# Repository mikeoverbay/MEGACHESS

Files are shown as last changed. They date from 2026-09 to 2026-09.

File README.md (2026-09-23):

# Megachess

Chess on an Arduino Mega 2560 R3 with the DIYables 3.5" 480x320 touch shield.

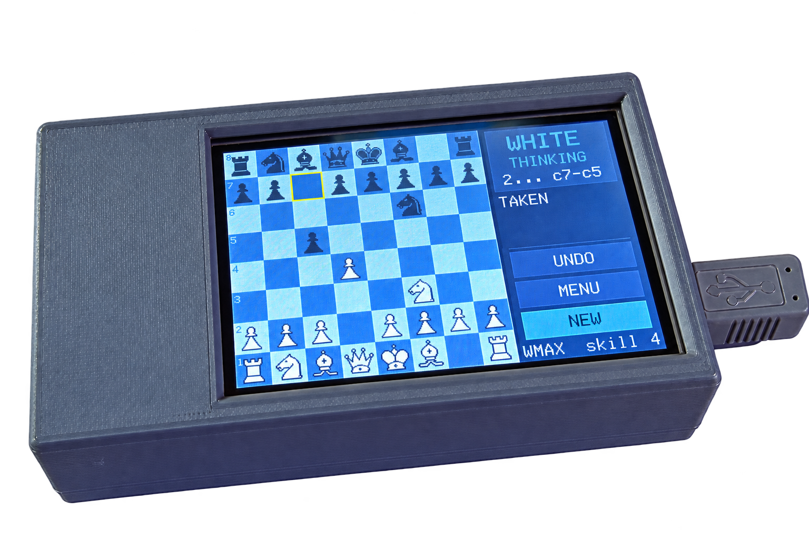
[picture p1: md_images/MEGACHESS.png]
Megachess in its case, mid-game


Tap a piece, tap where it goes. Play the engine, play a friend on the one
screen, or let the engine play itself. Five board themes, a saved game you can
resume after a power cut, a PGN log of every finished game, and an opening book
— the last three from the SD card.

| | |
|---|---|
| rules, and the search at SKILL 1–2 | [MicroChess](https://github.com/ripred/MicroChess) by Trent M. Wyatt, MIT, in `src/engine` |
| the search at SKILL 3–7 | [micro-Max 4.8](http://home.hccnet.nl/h.g.muller/max-src2.html) by H.G. Muller, in `src/umax` |
| display and touch | DIYables_TFT_Touch_Shield 2.2.1 |
| artwork, UI, storage, engine glue | this sketch |

Built for `arduino:avr:mega`. Current size: **76.4 KB flash (30%)**, **4729 B
RAM (57%)**, leaving 3.4 KB for the searches' recursion; micro-Max was measured
using up to 1.9 KB of that.

---

## Parts

| part | notes |
|---|---|
| Arduino Mega 2560 R3 | the 256 KB of flash and the SPI on pins 50–52 are why it is a Mega and not an Uno |
| DIYables 3.5" 480x320 TFT touch shield | resistive touch, microSD slot; HX8357D driver on current units, RM68140 on earlier ones ([product page](https://diyables.io/products/3.5-320x480-tft-lcd-color-touch-screen-shield-for-arduino-uno-mega)) |
| microSD card | any size from 1 GB up, FAT32 with MBR; it needs under half a megabyte. Built with a 16 GB card. Plus a reader for the PC |
| 3 short wires, soldered | on the underside of the Mega, pins 50, 51, 52 to D12, D11, D13 — see below. The case leaves no room for jumper wires on the headers |
| USB A-to-B cable | powers it and programs it |
| stylus | optional; a fingernail works on the resistive panel |
| the printed case | two parts, see [The case](#the-case) |

Software: Arduino IDE 2 (its bundled arduino-cli does the builds here), the
DIYables_TFT_Touch_Shield library 2.2.1 and the SD library 1.3.0, Python 3 with
Pillow for the tools (skia-python as well to re-render the piece art), and,
only for the simulator, Visual Studio's C++ compiler.

---

## Building it

### In the Arduino IDE

1. Get the folder onto your machine, as a clone or a zip, and keep its name
   `Megachess`: the IDE wants the folder and its `.ino` to match.
2. **Tools > Board > Arduino AVR Boards > Arduino Mega or Mega 2560**, and
   **Tools > Port** to the Mega.
3. **Sketch > Include Library > Manage Libraries**, search
   *DIYables_TFT_Touch_Shield*, install **2.2.1**. The SD library comes with
   the IDE.
4. Open `Megachess.ino`. The engines in `src/engine` and `src/umax` compile
   along with it; nothing to add.
5. Check `megachess.h` names your shield's driver (see *Run this first*),
   then **Upload**.

The Serial Monitor at 115200 shows the boot report, and while you play, one
line per engine move. Close it before an upload if the upload times out: it
holds the port.

The other sketches open the same way: `bringup/bringup.ino`, and
`umaxbench/umaxbench.ino` after running `sh tools/umax_bench.sh` once, which
copies the engine into it.

### From the command line

The IDE bundles `arduino-cli`; every command below works with it. Compile
and upload the game:

```bash
arduino-cli compile -b arduino:avr:mega --upload -p COM8 .
```

## Run this first

```bash
arduino-cli compile -b arduino:avr:mega --upload -p COM8 bringup
```

`bringup/bringup.ino` answers the three things that have to be true before the
game is worth running.

**1. Which driver IC?** DIYables ship this board with an RM68140 (early units)
or an HX8357D (later ones, after a chip shortage). Both use library 2.x and
share an API — only the class name differs, and the wrong one gives a blank or
garbled screen. The sketch paints a card for each; tap whichever renders
correctly and it prints the line to paste into `megachess.h`:

```c
#define MEGACHESS_DRIVER_RM68140     // or MEGACHESS_DRIVER_HX8357D
```

The default is RM68140. If *neither* card renders, you have the older,
discontinued ILI9488 shield, which needs library **v1.0.0** instead — that
version has the `DIYables_TFT_ILI9488_Shield` class this one dropped.

**2. Does touch land where you press?** After you tap, it switches to a touch
test with corner targets. If the crosshair sits off them, run the library's
`TouchCalibration` example and paste its four numbers into `ui_begin()` in
[ui.cpp](ui.cpp).

**3. Is the SD card reachable?** Checked at boot, reported on Serial at 115200.
Expect it to fail until you add three wires — see below.

---

## The SD card needs three jumpers on a Mega

This is DIYables' own note, not a fault:

> On Arduino Mega, the microSD card slot (D10–D13) does not work without extra
> wiring because the Mega's SPI pins are on D50–D53.

The shield's SD lines sit on the Uno SPI footprint. The Mega's hardware SPI is
elsewhere, so bridge them:

| Mega pin | to shield pin | signal |
|---|---|---|
| 50 | D12 | MISO |
| 51 | D11 | MOSI |
| 52 | D13 | SCK |
| — | D10 | CS — ordinary GPIO, already fine |

Jumper wires on the headers will do for a test on the bench, but the case
has no room for them: solder three short wires on the underside of the Mega,
from the pads of 50, 51 and 52 to the pads of D12, D11 and D13.

**Everything works without the card.** You lose the SD-loaded artwork (the
built-in 1-bit pieces stand in), saving, the PGN log and the opening book. The
chess is untouched.

### What goes on the card

FAT32, MBR — which is what yours already is. Written for you:

```
/PIECES/AMBER.SET        full-colour piece artwork, one per theme
/PIECES/CLASSIC.SET
/PIECES/POCKET.SET
/PIECES/SLATE.SET
/PIECES/VECTOR.SET
/MCHESS/BOOK.TXT         opening lines, editable
/MCHESS/SAVE.DAT         written as you play, removed when a game ends
/MCHESS/SETTINGS.DAT     mode, skill, theme, orientation, touch calibration
/MCHESS/GAMES.PGN        every finished game, appended
/IMAGES/SPLASH.IMG       boot picture, optional: tools/LOGO.png through tools/splash.py
```

`SD_DATA/` in the repo is this card, file for file; copy it over. MCHESS is
the firmware's own folder and it creates it; IMAGES is yours. Every name
is 8.3 on purpose: the Arduino SD library cannot open anything longer, folders
included, and it fails without a word. The folder was MEGACHESS once, and the
Mega never read or wrote a byte in it. The simulator refuses such names too.

---

## Playing

**Menu.** Mode (vs engine / 2 player / engine demo), skill 1–7 (1–2 is
MicroChess searching that many plies, 3–7 is micro-Max on a clock of 1, 2.5, 5,
10 or 20 seconds — the label says which), which colour you take, theme, board
orientation. `RESUME` lights up when the card
holds an unfinished game.

**Board.** Tap a piece to pick it up — its legal destinations appear as dots,
and a circle around each piece it can take. Tap a destination to play it, tap the
piece again to put it down, or tap another of your pieces to switch. The last
move keeps an amber border; a king in check gets a red one.

**UNDO** steps back a full move in vs-engine mode (yours *and* the engine's
reply), one half-move otherwise. Four half-moves are kept.

Pawns auto-queen — the engine has no underpromotion, so there is no piece
picker to show you.

### A quirk worth knowing

MicroChess scores "moved and left my own king attacked" as an immediate loss
rather than an illegal move. That is fine for the engine, but it would mean a
mis-tap loses you the game, so `apply_move()` plays the move, checks your king,
and takes it straight back with **KING IN CHECK** if it hangs.

The move dots are the engine's pseudo-legal list, so a square that would hang
your king still shows a dot. Filtering them properly needs a trial move per
destination — about a second per piece on a 16 MHz AVR — which is why the check
happens on the tap instead.

---

## Themes and artwork

Five themes, switchable from the menu, defaulting to **Amber**. Board colours
live in [themes_gen.h](themes_gen.h); the matching pieces are on the card.

The card artwork is the **Alpha** chess set by Eric Bentzen, as shipped in
lichess (`public/piece/alpha`, free to use), rasterised per theme by
[tools/svgpieces.py](tools/svgpieces.py): each SVG's fills and strokes are
substituted with the theme's piece colours, rendered at 8x through Skia, and
LANCZOS-downsampled to 40x40. To rebuild after a theme change:

```bash
python tools/svgpieces.py alpha alpha H:\PIECES
```

Card artwork is 40x40 RGB565 **with an alpha channel**, blended against the
square underneath as it is drawn. That is why pieces have clean antialiased
edges on both light and dark squares — a colour-key cutout cannot do that. The
built-in fallback is three 1-bit layers (body, rim, internal detail), which
keeps a black piece reading as a dark silhouette rather than a light-outlined
one on a light square.

To change colours or add a theme, edit `THEMES` in [tools/themes.py](tools/themes.py) and:

```bash
python tools/build_assets.py H:\
```

That rewrites the `.SET` files, `pieces_bmp.h` and `themes_gen.h` from the one
table, so the card and the firmware cannot drift apart. `python tools/mock2.py`
renders PNG mockups at the real 480x320 to check a theme without flashing.

---

## The opening book

`/MCHESS/BOOK.TXT` — one opening per line, long algebraic, `#` for comments:

```
e2e4 e7e5 g1f3 b8c6 f1c4 g8f6 d2d3 f8c5 c2c3 d7d6
d2d4 g8f6 c2c4 g7g6 b1c3 f8g7 e2e4 d7d6 g1f3 e8g8
```

When the game so far matches the start of a line, the engine plays that line's
next move, choosing at random among all matching lines so it varies. Once play
leaves the book it stops looking and searches normally.

The 33 shipped lines were checked move-by-move with `python-chess` — 330 plies,
all legal. Lines you add are *not* validated: an illegal move is ignored and
the engine searches instead.

This replaces MicroChess's built-in book, which was one hard-coded line for one
side (`options.openbook` is left off).

---

## PGN log

Finished games append to `/MCHESS/GAMES.PGN`. Moves are written in **long
algebraic** (`e2e4`, `Nb1c3`, `Bf1xc4`), not strict SAN — it needs no
disambiguation pass, and lichess, SCID and ChessBase all import it. If you want
strict SAN, the place to add it is `lan()` in [storage.cpp](storage.cpp).

---

## Two engines

MicroChess is the rules. It generates the move list you see as dots, plays
every move, and detects check, mate and repetition. At SKILL 1 and 2 it also
chooses the engine's move, searching 1 or 2 plies.

From SKILL 3 up the move comes from micro-Max 4.8, H.G. Muller's engine in
under 2 KB of C, in `src/umax`. On the engine's turn the position is copied
onto micro-Max's own 0x88 board, it searches for the level's clock, and the
move it names is played through MicroChess exactly as a human's would be:
checked against MicroChess's move list for that piece first. Should the two
ever disagree, MicroChess's own search decides and a line saying so goes to
Serial. In a 126-move simulator game between two micro-Max sides that never
happened.

The Mega runs micro-Max at about 700 nodes a second. Measured with
`umaxbench`: a 2.5 s clock reaches depth 3 to 4, a 10 s clock depth 4 to 5.
The clock is a budget, not a limit. The engine starts another pass while less
than a third of it has gone, and a hard stop at one and a half times the
budget unwinds the search with the best move so far. Touching the panel while
it thinks does the same, so MENU works mid-think.

Each micro-Max move prints one line to Serial at 115200: depth, score, nodes,
time, and how close the stack came to the heap.

`sh tools/umax_bench.sh -u -p COM8` builds and uploads `umaxbench`, a self-play
benchmark that prints those figures for two clocks.

`src/umax/umax.cpp` is the upstream text line for line with every change marked
`MEGA`; its header lists them: a 128-entry hash with 32-bit keys, the key table
in flash, time-based deepening with a hard stop, the repetition locks moved out
of the search into a short list that recycles its oldest entry, and the console
I/O replaced by the calls in `umax.h`. The author publishes the source on his site for people to learn from
and port, with no formal licence text; chessprogramming.org lists it as open
source, and ports such as [mcu-max](https://github.com/Gissio/mcu-max) release
theirs under MIT. This copy keeps the file header, feature list and URL intact
and claims nothing beyond the changes marked `MEGA`.

---

## Two patches to the engine

`src/engine` is upstream MicroChess apart from these. Both are marked
`// Megachess:` in the source.

**1. The debug pins are the display bus.** Upstream drives LEDs on 3, 4, 5, 8
and a WS2811 strip on 6 — every one of those is part of the shield's 8-bit
parallel data bus. `MicroChess.h` sets them all to `0xFF`, and `direct_write()`
in `chessutil.cpp` returns early on that value. Without it, `direct_write()`'s
raw `PORTD`/`PORTB` writes land on whatever those bits are on a Mega, which is
not where the Uno pin numbers point.

**2. `led_strip.cpp` is stubbed.** Its FastLED path compiles on AVR and
`FastLED.show()` bit-bangs pin 6 — D6 of the display bus — mid-render. The stub
also drops FastLED's 192-byte `leds[]` array.

`MicroChess.ino` became `engine.cpp` with `setup()`/`loop()` removed (the
upstream `setup()` runs an entire game, blocking on Serial for human moves).
Two forward declarations were added: as a `.ino` the Arduino build hoisted a
prototype for every function, and a `.cpp` gets no such favour.

Everything else — move generation, alpha-beta, quiescence, castling, en
passant, repetition — is untouched upstream code.

---

## The case

Two parts in `case/`, the author's own design in Shapr3D for exactly this
stack: a Mega 2560 with the shield on it.

| file | outside size | triangles |
|---|---|---|
| [top.stl](case/top.stl) | 113.9 x 66.3 x 20.0 mm | 9,460 |
| [bottom.stl](case/bottom.stl) | 113.9 x 66.3 x 9.6 mm | 60,528 |

Open either file on GitHub and it shows in 3D: drag to turn it, and the
toolbar switches to wireframe.

`case.step` is the model itself, both parts, straight out of Shapr3D, for
anyone who wants to change it: a STEP opens in any CAD program as solids,
where an STL is only the skin.

Closed it is 113.9 x 66.3 x 29.6 mm, about 6 mm around the Mega's 101.6 x
53.3 mm board. The top is the shell: a window for the screen and two cut-outs
on the short end for the USB socket and the power jack. The bottom is the
plate: four posts for the Mega's mounting holes, slots for air, and a rim that
registers inside the top.

`case.gcode` is both parts on one bed, sliced in Cura 5.2.1 for a Creality
Ender 3 Pro (Marlin flavour): 0.2 mm layers, 10% grid infill, no supports,
225 °C nozzle, 50 °C bed, 15.8 m of filament, 3 h 44 min. It prints a draft
shield 6 mm out from the parts and 10 mm high, which keeps the corners from
curling as the print shrinks. `case.3mf` is the Cura project behind it: both
parts placed on the bed with every setting, so a different printer or
filament is one change and a reslice.

---

## Layout

```
Megachess.ino     app state machine, engine glue, setup/loop
megachess.h       geometry, theme struct, cross-file API
ui.cpp            board, panel, menu, hit testing
storage.cpp       SD: artwork, settings, save/resume, PGN, book
themes_gen.h      generated - theme table
pieces_bmp.h      generated - 1-bit fallback artwork
bringup/          hardware bring-up sketch, run first
tools/            asset generators, the mockup renderer, the micro-Max key
                  table generator and benchmark script
umaxbench/        micro-Max speed and stack benchmark for the Mega
case/             the printed case: STEP model, two STL parts, Cura project, sliced gcode
src/engine/       MicroChess
src/umax/         micro-Max 4.8, fitted to the AVR
```

Screen is 480x320 landscape (rotation 1): board 320x320 at 40px a square,
panel 160 wide on the right. The 40px square is why pieces blit with no
scaling.

When the engine moves, the square it leaves flips to the opposite square
colour three times with the piece still on it, the board repaints, and the
square it lands on flips three times. Your own moves get no announcement.

### RAM

`UNDO_SLOTS` in `megachess.h` is 4. Each slot is a `board_t` + `game_t`
snapshot, so raising it costs real memory — and the engine checks free RAM at
runtime to decide how deep to search (`options.low_mem_limit`, 810 bytes), so
squeezing the stack makes it play *worse*, quietly. Re-read the compiler's RAM
line after changing it.

`src/umax` adds 1.4 KB of globals: the hash table (`U` entries of 9 bytes in
`umax.cpp`, 128 of them), the board, and a list of the last 24 game positions
for repetition detection. Doubling `U` to 256 left
2.3 KB for the stack, and micro-Max alone was measured using up to 1.9 KB of it
on a 10 s clock, so 128 it is.

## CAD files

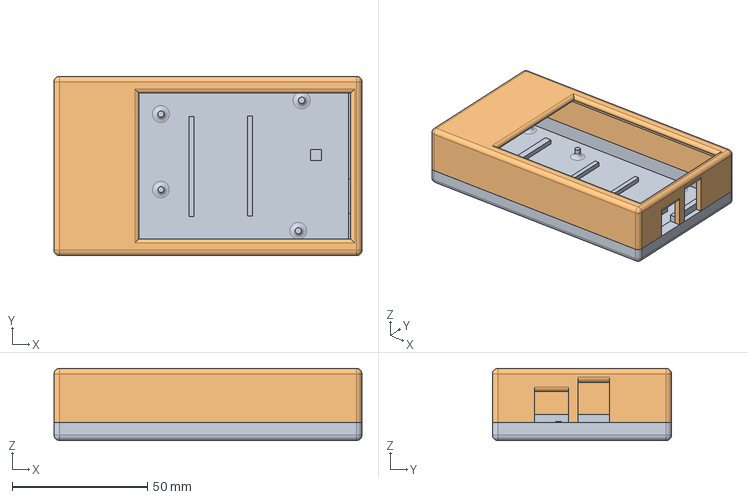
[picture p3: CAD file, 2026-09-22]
case/case.step
113.9 x 66.3 x 26.6 mm

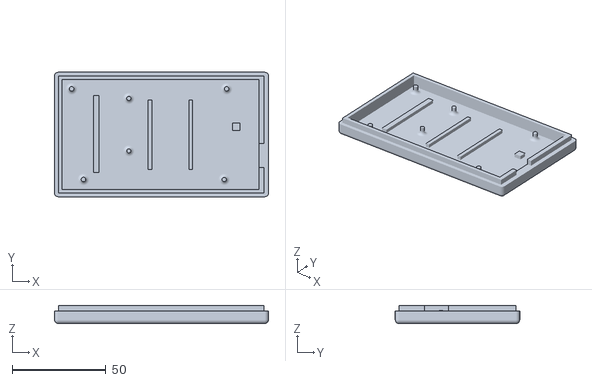
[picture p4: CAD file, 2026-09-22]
case/bottom.stl
113.9 x 66.3 x 9.64

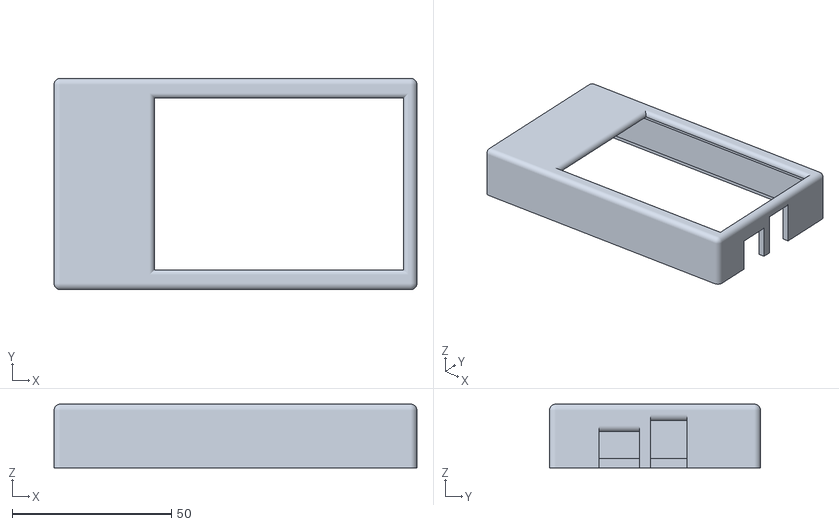
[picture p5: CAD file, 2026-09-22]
case/top.stl
113.9 x 66.3 x 20.0

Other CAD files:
case/case.3mf

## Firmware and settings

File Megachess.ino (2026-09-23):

/*
 * Megachess - chess on an Arduino Mega 2560 with the DIYables 3.5" 480x320
 * touch shield.
 *
 *   rules + search   MicroChess by Trent M. Wyatt, in src/engine (MIT)
 *   display + touch  DIYables_TFT_Touch_Shield
 *   artwork, UI, storage, engine glue   this sketch
 *
 * Run bringup/bringup.ino FIRST. It tells you which driver IC your shield has
 * (paste the line it prints into megachess.h), whether touch lands where you
 * press, and whether the SD slot is reachable. See README.md.
 *
 * The engine's own take_turn() blocks on Serial for a human move, so this
 * sketch does not use it; apply_move() and ai_move() below drive the same
 * engine pieces non-interactively. Everything else in src/engine is upstream
 * apart from two documented safety patches - see README.
 */
#include <SD.h>
#include "megachess.h"
#include "src/umax/umax.h"

Panel    tft;
// board and game are defined by the engine itself, in src/engine/engine.cpp -
// megachess.h only declares them extern.

// Calibration zeros mean "never calibrated" - the library defaults apply
// until the CAL button on the menu is used.
Settings settings = { SETTINGS_MAGIC, MODE_HUMAN_AI, 4 /* micro-Max, 2.5 s */, White, 0,
                      1 /* AMBER */, 0, 0, 0, 0 };
AppScreen screen = SCR_MENU;

// ---------------------------------------------------------------------------
// SKILL. Levels 1 and 2 are MicroChess searching that many plies. From
// SKILL_FIRST_UMAX up the move comes from micro-Max on a clock, and MicroChess
// only keeps the rules (and steps in if the two ever disagree).
// ---------------------------------------------------------------------------
static const uint16_t UMAX_BUDGET_MS[SKILL_MAX - SKILL_FIRST_UMAX + 1] PROGMEM =
    { 1000, 2500, 5000, 10000, 20000 };

static bool skill_uses_umax() { return settings.ply >= SKILL_FIRST_UMAX; }

static uint16_t skill_budget_ms() {
    uint8_t i = settings.ply - SKILL_FIRST_UMAX;
    if (i > SKILL_MAX - SKILL_FIRST_UMAX) i = SKILL_MAX - SKILL_FIRST_UMAX;
    return pgm_read_word(&UMAX_BUDGET_MS[i]);
}

uint8_t legal_mask[8];
index_t sel_from  = -1;
index_t last_from = -1, last_to = -1;
bool    ai_thinking = false;
int16_t tap_x = -1, tap_y = -1;   // last tap, for the on-screen readout

// ---------------------------------------------------------------------------
// undo. Each slot is a full board + game snapshot; the newest also serves as
// the scratch copy for the "does this move leave my own king in check" trial,
// so a rejected move costs nothing extra.
// ---------------------------------------------------------------------------
struct Snapshot {
    board_t b;
    game_t  g;
    index_t lf, lt;
};
static Snapshot undoRing[UNDO_SLOTS];
static uint8_t  undoCount = 0, undoHead = 0;

static void push_undo() {
    undoRing[undoHead].b  = board;
    undoRing[undoHead].g  = game;
    undoRing[undoHead].lf = last_from;
    undoRing[undoHead].lt = last_to;
    undoHead = (undoHead + 1) % UNDO_SLOTS;
    if (undoCount < UNDO_SLOTS) undoCount++;
}

static bool pop_undo() {
    if (!undoCount) return false;
    undoHead = (undoHead + UNDO_SLOTS - 1) % UNDO_SLOTS;
    board     = undoRing[undoHead].b;
    game      = undoRing[undoHead].g;
    last_from = undoRing[undoHead].lf;
    last_to   = undoRing[undoHead].lt;
    undoCount--;
    return true;
}

// ---------------------------------------------------------------------------
bool side_is_human(Color side) {
    switch (settings.mode) {
        case MODE_HOTSEAT: return true;
        case MODE_AI_AI:   return false;
        default:           return side == settings.humanSide;
    }
}

static void apply_options() {
    game.options.print_level        = None;      // the panel is the output
    // With micro-Max choosing, MicroChess searches only as a fallback: keep it quick.
    const uint8_t ply = skill_uses_umax() ? 2 : settings.ply;
    game.options.maxply             = ply;
    game.options.minply             = 1;
    game.options.max_max_ply        = ply + 2;
    game.options.max_quiescent_ply  = ply + 2;
    game.options.time_limit         = 2500;      // ms - also caps how
                                             // long touch is ignored
    game.options.live_update        = True;      // drives the thinking spinner
    game.options.openbook           = False;     // the SD book replaces it
    game.options.random             = True;
    game.options.shuffle_pieces     = True;
    game.options.integrate          = True;
    game.options.alpha_beta_pruning = True;
    game.options.continuous         = False;
    game.options.profiling          = False;
    game.options.mistakes           = 0;
    game.options.randskip           = 0;
    game.options.white_human        = side_is_human(White);
    game.options.black_human        = side_is_human(Black);
}

static void new_game() {
    board.init();
    game.init();
    apply_options();
    game.sort_pieces(game.turn);
    game.shuffle_pieces(SHUFFLE);

    sel_from  = -1;
    last_from = last_to = -1;
    undoCount = undoHead = 0;
    memset(legal_mask, 0, sizeof(legal_mask));

    sd_book_reset();
    sd_pgn_begin();
    umax_new_game();
}

// ---------------------------------------------------------------------------
// legal destinations for one square
//
// choose_best_moves() enumerates every move for every piece and hands each to
// a callback. Passing our own instead of consider_move() gives the move list
// without any of the search: nothing calls make_move(), so the board is not
// touched and it returns in milliseconds.
//
// These are the engine's own pseudo-legal moves, so a destination that would
// leave your king in check is still shown. That case is caught when the move
// is actually played - see apply_move().
// ---------------------------------------------------------------------------
static index_t collect_from;

static void collect_cb(piece_gen_t& gen) {
    if (gen.move.from == collect_from && gen.move.to >= 0 && gen.move.to < 64)
        setbit(legal_mask, gen.move.to);
}

static game_t mask_saved;      // static, not on the stack: game_t is big

static void build_legal_mask(index_t from) {
    memset(legal_mask, 0, sizeof(legal_mask));
    collect_from = from;

    // choose_best_moves() is not a read-only query. At ply 0 it declares
    // STALEMATE or CHECKMATE from the move counts it gathered, and it also
    // writes king locations, timeout flags and move counters. Letting any of
    // that survive a scan whose only job is to list one piece's destinations
    // ended the game the moment you picked a piece up - after which no move
    // could ever validate, because consider_move() returns immediately once
    // state != PLAYING.
    mask_saved = game;

    // take_turn() starts the move clock before calling this; without it
    // timeout() measures against a stale timestamp and aborts the walk early,
    // so most pieces came back with no legal moves at all.
    game.stats.start_move_stats();
    game.stats.move_stats.depth = 0;
    game.alpha = MIN_VALUE;
    game.beta  = MAX_VALUE;
    game.supply_valid  = False;
    game.user_supplied = False;
    game.book_supplied = False;

    move_t wmove = { -1, -1, MIN_VALUE };
    move_t bmove = { -1, -1, MAX_VALUE };
    choose_best_moves(wmove, bmove, collect_cb);

    game = mask_saved;
}

// ---------------------------------------------------------------------------
// playing a move
// ---------------------------------------------------------------------------
// Mirrors the commit half of the engine's take_turn().
static void commit(move_t& mv, move_t& wmove, move_t& bmove, bool whitesTurn) {
    game.last_move = mv;
    const index_t before = game.piece_count;

    piece_gen_t gen(mv, wmove, bmove, consider_move, False);
    gen.move = mv;
    gen.init(board, game);
    make_move(gen);
    check_kings();

    if ((PLAYING == game.state) && add_to_history(gen.move))
        game.state = whitesTurn ? WHITE_3_MOVE_REP : BLACK_3_MOVE_REP;

    // The engine scores "moved and left my own king attacked" as an immediate
    // loss. For the engine's own moves that stands; for a human's it is caught
    // by the caller and the move is taken back instead.
    if (whitesTurn && game.white_king_in_check)  game.state = BLACK_CHECKMATE;
    if (!whitesTurn && game.black_king_in_check) game.state = WHITE_CHECKMATE;

    game.turn = !game.turn;
    game.move_num++;

    if (before != game.piece_count) {
        for (index_t i = 0; i < game.piece_count; i++) {
            if (game.pieces[i].x == -1) {
                game.pieces[i] = game.pieces[--game.piece_count];
                break;
            }
        }
    }
}

// Does the side to move have any legal move? MicroChess only ever lists
// pseudo-legal moves and only calls mate for the engine's own side, so this
// tries each candidate for real and takes it straight back. Used to call
// mate or stalemate on a human, and to keep the engine's fallback legal.
// About 30 trial moves at a few ms each; the mask is cleared afterwards.
static bool find_legal_move(index_t& from, index_t& to) {
    const bool whitesTurn = (game.turn == White);
    move_t wmove = { -1, -1, MIN_VALUE };
    move_t bmove = { -1, -1, MAX_VALUE };
    // A trial is one make_move, no search behind it.
    const uint8_t mp = game.options.maxply, mq = game.options.max_quiescent_ply,
                  mm = game.options.max_max_ply;
    game.options.maxply = 0; game.options.max_quiescent_ply = 0; game.options.max_max_ply = 0;
    bool found = false;
    for (index_t sq = 0; sq < 64 && !found; sq++) {
        const Piece p = board.get(sq);
        if (isEmpty(p) || getSide(p) != game.turn) continue;
        build_legal_mask(sq);
        for (index_t t = 0; t < 64; t++) {
            if (!(getbit(legal_mask, t))) continue;
            push_undo();
            game.stats.start_move_stats();
            game.stats.move_stats.depth = 0;
            reset_turn_flags();
            game.alpha = wmove.value;
            game.beta  = bmove.value;
            game.supplied      = move_t(sq, t, 0L);
            game.user_supplied = True;
            game.supply_valid  = True;
            move_t mv = game.supplied;
            commit(mv, wmove, bmove, whitesTurn);
            const bool selfCheck = whitesTurn ? game.white_king_in_check
                                              : game.black_king_in_check;
            pop_undo();
            if (!selfCheck) { from = sq; to = t; found = true; break; }
        }
    }
    game.options.maxply = mp; game.options.max_quiescent_ply = mq; game.options.max_max_ply = mm;
    memset(legal_mask, 0, sizeof(legal_mask));
    return found;
}

// After a move has been played: if the side now to move has no legal move
// the game is over. This is the only way a human is ever mated here.
static void settle_side_to_move() {
    if (game.state != PLAYING) return;
    index_t f, t;
    if (!find_legal_move(f, t)) call_no_moves();
}

// No legal move: mate if in check, else stalemate. Sets game.state.
static void call_no_moves() {
    const bool whitesTurn = (game.turn == White);
    const bool inCheck = whitesTurn ? game.white_king_in_check : game.black_king_in_check;
    if (inCheck) game.state = whitesTurn ? BLACK_CHECKMATE : WHITE_CHECKMATE;
    else         game.state = STALEMATE;
}

static MoveResult apply_move(index_t from, index_t to) {
    const bool  whitesTurn = (game.turn == White);
    const Piece moved      = board.get(from);
    const bool  capture    = !isEmpty(board.get(to));

    // Validate against the engine's own move list for THIS piece - the very
    // list the destination dots were drawn from - with no search in the path.
    //
    // Validating through choose_best_moves(consider_move) meant a full
    // alpha-beta search of every piece that happened to sit before this one
    // in the shuffled pieces[] list, and consider_move() has three early
    // returns ahead of its supplied-move check (check_mem, state, and
    // supply_valid) that could fire during that unrelated search and reject
    // a perfectly legal move. The dots and the verdict now come from the
    // same scan, so they cannot disagree.
    build_legal_mask(from);
    // getbit() is a bare `a & b` with no outer parentheses, so it must be
    // wrapped before `!` - otherwise `!a & b` parses as `(!a) & b`.
    const bool legal = (getbit(legal_mask, to)) != 0;
    if (!legal) return MV_ILLEGAL;

    push_undo();

    move_t wmove = { -1, -1, MIN_VALUE };
    move_t bmove = { -1, -1, MAX_VALUE };

    game.stats.start_move_stats();
    game.stats.move_stats.depth = 0;
    reset_turn_flags();                     // clears the supplied-move flags
    game.alpha = wmove.value;
    game.beta  = bmove.value;

    game.supplied      = move_t(from, to, 0L);
    game.user_supplied = True;
    game.supply_valid  = True;              // validated above

    move_t mv = game.supplied;
    commit(mv, wmove, bmove, whitesTurn);
    game.stats.stop_move_stats();

    const bool selfCheck = whitesTurn ? game.white_king_in_check
                                      : game.black_king_in_check;
    if (selfCheck) { pop_undo(); return MV_SELF_CHECK; }

    last_from = mv.from;
    last_to   = mv.to;
    sd_pgn_move(mv.from, mv.to, moved, capture);
    return MV_OK;
}

// ---------------------------------------------------------------------------
// micro-Max as the move chooser (SKILL >= SKILL_FIRST_UMAX)
//
// The position is copied onto micro-Max's own board, it searches on a clock,
// and the move it names is played through MicroChess exactly like a human's:
// validated against MicroChess's own move list for that piece first. If the
// two ever disagree, MicroChess's search decides instead.
// ---------------------------------------------------------------------------
static bool umax_tick() {
    ui_think_tick();
#ifdef SIM
    return false;                 // the simulator queues taps ahead of time
#else
    int tx, ty;
    return touch_read(tx, ty);  // a finger on the panel ends the think early
#endif
}

static bool umax_pick(index_t& from, index_t& to) {
    umax_clear_board();
    for (index_t i = 0; i < 64; i++) {
        const Piece p = board.get(i);
        if (isEmpty(p)) continue;
        const uint8_t row = i >> 3, col = i & 7;
        const bool white = (getSide(p) == White);
        uint8_t code;
        switch (getType(p)) {
            case Pawn:
                code = white ? UMAX_WPAWN : UMAX_BPAWN;
                // Off its start rank it has moved; on its 6th/7th it is worth more.
                if (row != (white ? 6 : 1)) code |= UMAX_MOVED;
                if (row == (white ? 2 : 5)) code |= UMAX_RANK6;
                if (row == (white ? 1 : 6)) code |= UMAX_RANK7;
                break;
            case Knight: code = UMAX_KNIGHT | UMAX_MOVED; break;
            case Bishop: code = UMAX_BISHOP | UMAX_MOVED; break;
            case Queen:  code = UMAX_QUEEN  | UMAX_MOVED; break;
            case Rook:   code = UMAX_ROOK; if (hasMoved(p)) code |= UMAX_MOVED; break;  // castling rights
            default:     code = UMAX_KING; if (hasMoved(p)) code |= UMAX_MOVED; break;
        }
        code |= white ? UMAX_WHITE : UMAX_BLACK;
        umax_put(UMAX_SQ(row, col), code);
    }

    // En passant is on when the last move was a pawn's double step.
    uint8_t ep = UMAX_NO_EP;
    if (last_from >= 0 && last_to >= 0) {
        const Piece  lp = board.get(last_to);
        const int8_t dr = (int8_t) (last_to >> 3) - (int8_t) (last_from >> 3);
        if (!isEmpty(lp) && getType(lp) == Pawn && (dr == 2 || dr == -2))
            ep = UMAX_SQ((last_from >> 3) + dr / 2, last_to & 7);
    }
    umax_set_position(game.turn == White, ep);

#ifdef SIM
    const uint8_t maxDepth = 5;   // simulated time stands still during a search
#else
    const uint8_t maxDepth = 20;
#endif
    UmaxResult r;
    if (!umax_think(skill_budget_ms(), maxDepth, r)) return false;
    Serial.print(F("uMAX d")); Serial.print(r.depth);
    Serial.print(F(" score ")); Serial.print(r.score);
    Serial.print(' '); Serial.print(r.nodes); Serial.print(F(" nodes "));
    Serial.print(r.ms); Serial.print(F(" ms, stack low "));
    Serial.println(umax_stack_low());
    from = (index_t) ((r.from >> 4) * 8 + (r.from & 7));
    to   = (index_t) ((r.to   >> 4) * 8 + (r.to   & 7));
    return true;
}
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
void loop() {
    // Touch FIRST, always. The engine-turn branch below returns every
    // iteration while it is the engine's move, and in DEMO mode that is every
    // iteration forever - so checking touch after it meant no button worked
    // and the only way out of a demo was the reset button.
    {
        int16_t tx, ty;
        if (get_tap(tx, ty)) {
            switch (screen) {
                case SCR_MENU: handle_menu(ui_hit_button(tx, ty)); break;
                case SCR_GAME: handle_game_touch(tx, ty);          break;
                case SCR_OVER:
                    if (ui_hit_button(tx, ty) == BTN_NEW) {
                        new_game();
                        screen = SCR_GAME;
                        ui_set_status(NULL, 0);
                        ui_draw_game();
                    } else {
                        screen = SCR_MENU;
                        ui_draw_menu();
                    }
                    break;
            }
            return;
        }
    }

    // The engine's turn.
    if (screen == SCR_GAME && game.state == PLAYING &&
        !side_is_human((Color) game.turn)) {

        ai_thinking = true;
        ui_set_status(F("THINKING"), cur.accent);

        const index_t oldFrom = last_from, oldTo = last_to;
        const MoveResult r = ai_move();
        ai_thinking = false;

        if (r == MV_NONE) {
            if (game.state == PLAYING) call_no_moves();   // mate or stalemate, whichever it is
        } else {
            // Show the move: three flips where the piece was, then three where
            // it went. The screen still shows the old position here, and the
            // piece that moved is now on last_to.
            const Piece moved = board.get(last_to);
            ui_blink_square(last_from, moved);
            redraw_after_move(oldFrom, oldTo);
            ui_blink_square(last_to, moved);
            ui_draw_square(last_to);                 // its border back
            sd_save_game();
            settle_side_to_move();       // the other side may now have no move at all
        }

        if (!check_game_over()) {
            ui_set_status(NULL, 0);
            if (game.white_king_in_check || game.black_king_in_check)
                ui_set_status(F("CHECK"), C_CHECK);
        }

        // Give touch a real window between engine moves. The loop polls once
        // per iteration, and an iteration here is a whole search - so in DEMO,
        // where every move is the engine's, a tap almost never coincided and
        // the only way out was the reset button.
        {
            const uint32_t until = millis() + 700;
            while ((int32_t) (millis() - until) < 0) {
                int16_t tx, ty;
                if (get_tap(tx, ty)) {
                    handle_game_touch(tx, ty);
                    break;
                }
            }
        }
        return;
    }

}

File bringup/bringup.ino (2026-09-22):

/*
 * Megachess - hardware bring-up
 *
 * Answers three questions about the DIYables 3.5" 480x320 touch shield on a
 * Mega 2560 before we trust the game code on it:
 *
 *   1. WHICH DRIVER IC?  DIYables shipped three revisions of this shield and
 *      the class has to match. The sketch cycles through the two that library
 *      v2.x supports, painting a full-screen card for each. Tap the screen
 *      while a card is up to lock that driver in.
 *
 *        - Text crisp, TL marker top-left, RED/GREEN/BLUE labels over
 *          matching swatches  ->  that is your driver, tap it.
 *        - Blank, garbled, mirrored, or red and blue swapped on BOTH cards
 *          ->  you have the older ILI9488 board. Nothing to tap; tell me and
 *              I will downgrade the library to v1.0.0, which has that class.
 *
 *   2. DOES TOUCH LAND WHERE YOU PRESS?  After you tap, it switches to a touch
 *      test: a crosshair follows your finger and raw + mapped coordinates go
 *      to Serial. Four corner targets show how far off calibration is.
 *
 *   3. IS THE SD CARD REACHABLE?  Checked once at boot, reported on Serial.
 *      NOTE: on a Mega this shield's microSD slot is NOT wired to the Mega's
 *      SPI pins - DIYables say so themselves. Without three jumpers it will
 *      fail here, and that is expected rather than a fault. See README.
 *
 * Serial monitor: 115200 baud.
 */

#include <DIYables_TFT_Touch_Shield.h>
#include <SD.h>

#define SD_CS 10

// RGB565
#define C_BLACK  0x0000
#define C_WHITE  0xFFFF
#define C_RED    0xF800
#define C_GREEN  0x07E0
#define C_BLUE   0x001F
#define C_YELLOW 0xFFE0
#define C_GREY   0x8410
#define C_DARK   0x18E3

DIYables_TFT_RM68140_Shield rm68140;
DIYables_TFT_HX8357D_Shield hx8357d;

typedef DIYables_TFT_Touch_Shield_Base Panel;

Panel*      panel   = NULL;   // NULL until the user taps a card
const char* drvName = NULL;

// ---------------------------------------------------------------------------

void sdCheck() {
  Serial.println(F("--- SD card ---"));
  pinMode(SD_CS, OUTPUT);
  if (SD.begin(SD_CS)) {
    Serial.println(F("SD.begin() OK. Root listing:"));
    File root = SD.open("/");
    while (true) {
      File e = root.openNextFile();
      if (!e) break;
      Serial.print(F("    "));
      Serial.print(e.name());
      if (e.isDirectory()) Serial.print(F("   <DIR>"));
      else { Serial.print(F("   ")); Serial.print(e.size()); Serial.print(F(" bytes")); }
      Serial.println();
      e.close();
    }
    root.close();
  } else {
    Serial.println(F("SD.begin() FAILED."));
    Serial.println(F("On a Mega this is expected until you jumper the shield's"));
    Serial.println(F("SD lines to the Mega's hardware SPI pins:"));
    Serial.println(F("    Mega 50 (MISO) -> shield D12"));
    Serial.println(F("    Mega 51 (MOSI) -> shield D11"));
    Serial.println(F("    Mega 52 (SCK)  -> shield D13"));
    Serial.println(F("    CS stays on D10 - no wire needed."));
    Serial.println(F("The game runs fine without a card; SD features just switch off."));
  }
  Serial.println();
}

// A full-screen identification card for one candidate driver.
void drawCard(Panel& p, const char* name) {
  p.begin();
  p.setRotation(1);                 // 480x320 landscape, same as the game
  p.fillScreen(C_DARK);

  // Orientation marker. If this block is not in the TOP-LEFT corner the
  // rotation is mirrored or flipped for this driver.
  p.fillRect(0, 0, 44, 30, C_YELLOW);
  p.setTextColor(C_BLACK);
  p.setTextSize(2);
  p.setCursor(6, 8);
  p.print(F("TL"));

  p.setTextColor(C_WHITE);
  p.setTextSize(2);
  p.setCursor(70, 10);
  p.print(F("driver test"));

  p.setTextSize(4);
  p.setCursor(70, 52);
  p.print(name);

  // Colour check. Wrong driver or a BGR/RGB mix-up swaps RED and BLUE.
  const uint16_t sw[3]  = { C_RED, C_GREEN, C_BLUE };
  const char*    lbl[3] = { "RED", "GREEN", "BLUE" };
  for (uint8_t i = 0; i < 3; i++) {
    int16_t x = 40 + i * 140;
    p.fillRect(x, 120, 120, 90, sw[i]);
    p.drawRect(x, 120, 120, 90, C_WHITE);
    p.setTextColor(C_WHITE);
    p.setTextSize(2);
    p.setCursor(x + 12, 222);
    p.print(lbl[i]);
  }

  p.setTextColor(C_YELLOW);
  p.setTextSize(2);
  p.setCursor(40, 262);
  p.print(F("Readable + correct?"));
  p.setTextColor(C_WHITE);
  p.setCursor(40, 288);
  p.print(F("TAP to lock it in"));
}

void drawTouchScreen() {
  panel->fillScreen(C_BLACK);
  panel->setTextColor(C_GREEN);
  panel->setTextSize(3);
  panel->setCursor(10, 8);
  panel->print(F("Driver: "));
  panel->print(drvName);

  panel->setTextColor(C_GREY);
  panel->setTextSize(1);
  panel->setCursor(10, 40);
  panel->print(F("Drag a finger. Coords also go to Serial."));
  panel->setCursor(10, 52);
  panel->print(F("Hit each corner target - the cross should sit on it."));

  // Corner targets to eyeball the calibration against.
  const int16_t cx[4] = { 20, 459, 20, 459 };
  const int16_t cy[4] = { 90, 90, 299, 299 };
  for (uint8_t i = 0; i < 4; i++) {
    panel->drawCircle(cx[i], cy[i], 12, C_YELLOW);
    panel->drawFastHLine(cx[i] - 16, cy[i], 32, C_YELLOW);
    panel->drawFastVLine(cx[i], cy[i] - 16, 32, C_YELLOW);
  }
}

// ---------------------------------------------------------------------------

void setup() {
  Serial.begin(115200);
  while (!Serial && millis() < 3000) { }
  Serial.println();
  Serial.println(F("=== Megachess bring-up ==="));
  sdCheck();
  Serial.println(F("--- Display ---"));
  Serial.println(F("Cycling driver cards. TAP the screen on whichever one"));
  Serial.println(F("renders correctly. If neither does, you have the older"));
  Serial.println(F("ILI9488 shield and need library v1.0.0."));
  Serial.println();
}
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

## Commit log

2026-09-22 Megachess: chess on a Mega 2560 with the DIYables 3.5" touch shield
    MicroChess engine (vendored in src/engine with three fixes: 5-bit loop
    counters that hung on a 32-piece board, pawns double-stepping over a
    blocker, and the debug/LED pins that are the display bus), a touch UI with
    Alpha piece artwork streamed from the SD card, save/resume, PGN log, opening
    book, five themes, and a native simulator that renders the real firmware
    for review before flashing.
    [Megachess.ino]
2026-09-22 Remove the Thingiverse case download's readme, licence and photos
    LICENSE.txt, README.txt and images/ belonged to dapostol73's "Arduino Mega
    with Screen Case" (thingiverse.com/thing:5983901), which was unpacked here
    while looking for an enclosure. They are not part of this project. The case
    model itself (top.stl, bottom.stl) stays untracked for now.
2026-09-22 micro-Max 4.8 chooses the engine's move from SKILL 3 up
    MicroChess stays the rules: move list, check, mate, repetition. From SKILL 3
    the move comes from H.G. Muller's micro-Max on a clock of 1 to 20 s, played
    through MicroChess like a human's move and checked against its move list
    first; if the two disagree MicroChess's own search decides. A finger on the
    panel stops a think early with the best move so far.
    src/umax/umax.cpp is the upstream text with every change marked MEGA: a
    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
2026-09-22 Status card keeps the side on top while the engine thinks
    It read THINKING over THINKING. Line one is now always WHITE or BLACK and
    THINKING sits under it as the status line. The simulator gained a
    showthinking script item to snap the card in that state.
    [main.cpp, ui.cpp]
2026-09-22 Simulator: showleave snaps the MENU dialog
    [main.cpp]
2026-09-22 Card folders MCHESS and IMAGES: the SD library is 8.3 only
    MEGACHESS is nine letters, and the Arduino SD library cannot open a name
    longer than eight, folder or file. It fails without a word, for reading as
    well as writing, so on the Mega no setting, save or PGN was ever written and
    the book and splash were never read. A boot probe that created a file in
    the root but not in the folder, with no card error, gave it away.
    The firmware's files now live in /MCHESS, which it creates itself; the
    splash comes from /IMAGES, the user's picture folder. RESUME explains itself
    on the menu footer when there is nothing to resume or the save is
    unreadable, and both save and resume say why on Serial. The si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
    [Megachess.ino, sdtest.ino, sdtest_soft.ino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]
2026-09-22 Boot straight to the logo: panel dark until the first screen is ready
    The start-up text and its clear are gone. ui_begin() leaves the display
    switched off (DCS 0x28), the logo is written into the panel's memory
    first thing after the card comes up, and the display is switched on with
    it complete. Without a card the menu is the first thing shown the same
    way. Builds and runs in the simulator; the panel itself is still to be
    seen, the board stopped answering before it could be flashed.
2026-09-22 Menu taps repaint only the part they changed
    The menu is drawn in parts - modes, skill, side, theme, board, actions -
    each covering its own footprint, and a tap repaints just the parts that
    depend on that setting: a mode change also refreshes skill and side, side
    also refreshes board. THEME still repaints the whole screen, since every
    colour follows it.
2026-09-22 Parts list, and the case with its two STL parts
    The README gains a parts table with the software beside it, and a section
    on the case: the author's own Shapr3D design in two parts, measured from
    the STLs (113.9 x 66.3 mm, 20 + 9.6 mm tall), with renders of each part
    and the Cura settings read out of the sliced gcode. case/ holds the STLs,
    the renders and the gcode.
    [bottom.stl, top.stl]
2026-09-22 The three SD wires are soldered under the Mega
    The case leaves no room for jumper wires on the headers, so the parts list
    and the wiring section say so: three short wires on the underside, pads of
    50, 51, 52 to the pads of D12, D11, D13.
2026-09-22 Let GitHub show the case in 3D
    The README links the two STL files instead of carrying flat renders of
    them; GitHub's own viewer turns them.
2026-09-22 The gcode is for an Ender 3 Pro and prints a draft shield
2026-09-22 The Cura project for the case
    case/case.3mf: both parts on the bed with every slicer setting, so the
    print can be redone for another printer or filament without rebuilding
    the setup from the README's numbers.
    [case.3mf]
2026-09-22 Boot banner reports the panel's pressure
    Ten raw touch readings at boot, the highest printed: a lid resting on the
    active area shows up here as a press with nobody touching.
2026-09-22 Touches within 8 px of the screen edge are ignored
    A case lid resting on the panel, or a thumb on the bezel, can only ever
    register at the very edge, and no target needs that strip. Every poll in
    the sketch goes through touch_read(), so such a press can neither hold a
    dialog's wait-for-release nor cut a search short. Calibration still reads
    the panel raw.
    [Megachess.ino]
2026-09-22 Menu paints over the logo: display-off shows white on this glass
    The panel is normally-white with the backlight always on, so switching
    the driver off between the logo and the menu gave a white flash instead
    of holding the logo. The trick stays for blank-to-picture only; the code
    says why.
2026-09-22 The case as a STEP model, for editing
    case/case.step, both parts out of Shapr3D, so the design can be changed
    in any CAD program rather than only reprinted.
    [case.step]
2026-09-23 False mates: the hash key lost the side to move, and mate is now called properly
    A demo game ended "Black mates" with six escapes on the board. Replaying
    it natively with a root trace showed micro-Max's search collapsing on that
    ply and reporting no move, after which MicroChess's own search played a
    move that ignored the check and the self-check rule declared mate against
    it.
    The collapse: upstream keeps the side to move in the hash slot only as
    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
2026-09-23 The finished thing: a photo at the top of the README
    Cut out from a desk photo along the case's own outline, transparent
    around it.
2026-09-23 README photo from md_images
    The user's own picture of the finished unit replaces my cut-out.
2026-09-23 README: building in the Arduino IDE
2026-09-23 File letters 6 px higher, clear of the case lip
2026-09-23 New photo of the device
2026-09-23 Engine moves announced by flipping the squares, rings gone
    Three flips of the square the piece leaves, with the piece still shown,
    then the board repaints and the landing square flips three times. The
    tap ripple and the thinking rings are removed; the think hook draws
    nothing now.
    [Megachess.ino, ui.cpp]
